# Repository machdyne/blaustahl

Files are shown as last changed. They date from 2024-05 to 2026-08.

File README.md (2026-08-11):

# Blaustahl Storage Device

The Blaustahl USB dongle provides long-term storage for 7,680 characters of text, backed by non-volatile FRAM memory — no batteries, no wear-out from repeated writes, and no risk of losing data if the device is unplugged. Simply plug it into your computer and open any serial communications program that supports VT100 emulation (PuTTY, Tera Term, Minicom, screen, etc.) to access the built-in editor.

Beyond the FRAM editor, Blaustahl also includes a small flash filesystem for storing files, a file browser and viewer, a built-in text editor, password-protected encryption, file transfer over XMODEM, and a full Scheme programming environment — all accessible over the same USB serial connection, no drivers or extra software required.

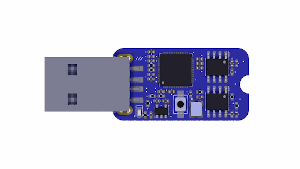
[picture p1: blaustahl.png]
Blaustahl


This repo contains schematics, PCB layouts, firmware, and a 3D-printable case.

Find purchasing information on the [Blaustahl product page](https://machdyne.com/product/blaustahl-storage-device/).

> **This is an early beta of firmware v0.1.0.** Most features described here are stable and well-tested, but as with any beta, please back up anything important and report anything that looks wrong. See firmware-0.0.x for the old firmware.

## Connecting Blaustahl

The following sections describe how to connect to Blaustahl on different operating systems. Once connected, press **CTRL-G** at any time to view the on-device help screen.

### Linux

1. Install screen or minicom:

```
$ sudo apt install screen
$ sudo apt install minicom
```

2. After plugging in Blaustahl, find the device:

```
$ dmesg | grep ACM
```

3. Connect to the device (for example):

```
$ screen /dev/ttyACM0
or
$ minicom -D /dev/ttyACM0
```

If the device is already plugged in and you see nothing, you may need to press CTRL-L to refresh the display.

### OS X

1. Open the Terminal application.

2. After plugging in Blaustahl, find the device:

```
$ ls /dev/tty.usbmodem*
```

3. Connect to the device (for example):

```
$ screen /dev/tty.usbmodem1234561
```

### Windows

1. Download and install [PuTTY](https://www.chiark.greenend.org.uk/~sgtatham/putty/latest.html).

2. After plugging in Blaustahl, find the device by opening Device Manager and looking under "Ports (COM & LPT)" for "USB Serial Device (COMx)".

3. Open PuTTY, set connection type to Serial, enter COMx (e.g. COM4) in the serial line box, and press Open.

## The menu bar

Everything in Blaustahl is reached from one menu bar across the top of the screen:

```
/// | EDITOR: [FRAM] [SRAM] | [VIEWER] [FILES] [CLI] [HELP] |   MODE: [TEXT] [HEX]
```

Press **CTRL-T**, **ESC-ESC**, or a single **ESC** (pause briefly) to open it from anywhere. Use the arrow keys to move between items and Enter to select one, or Esc to close the menu without changing anything.

- **FRAM** / **SRAM** — the built-in grid editor, for the device's permanent (FRAM) or temporary (SRAM) storage.
- **VIEWER** — a read-only viewer for files stored on the flash filesystem.
- **FILES** — browse and manage files on the flash filesystem.
- **CLI** — a command-line interface, including a full Scheme programming environment.
- **HELP** — the same help screen as CTRL-G.
- **MODE: TEXT / HEX** — switches how the grid editor displays data.

Pressing **CTRL-F** from anywhere jumps straight to FILES, skipping the menu.

## The grid editor (FRAM & SRAM)

The grid editor shows 7,680 bytes as a fixed 80x24 grid, split across four pages (PGUP/PGDN to flip between them — there's no scrolling within a page). Move the cursor with the arrow keys, or jump to the start/end of the current row with Home/End.

**FRAM** is the device's permanent, non-volatile storage — this is what survives being unplugged, and what the device is for. **SRAM** is a second, identical-sized scratchpad you can use the same way, but its contents are lost whenever the device is unplugged or power-cycled — a good place for anything temporary you don't want to persist.

| Keypress | Action |
| --- | --- |
| CTRL-W | Toggle write mode, or commit staged edits if editing encrypted FRAM |
| CTRL-B | Toggle buffer mode (see "Encryption" below) |
| CTRL-C | Start/finish copying: press once to mark the start, move the cursor to select, press again to copy |
| CTRL-V | Paste at the cursor |
| CTRL-S / CTRL-Q | Toggle the status bar |
| CTRL-L | Refresh the screen |
| CTRL-G | Help |
| PGUP / PGDN | Flip page |

By default the grid is read-only; press CTRL-W to enable editing. Whatever you type overwrites the byte under the cursor and the cursor advances — there's no insert/delete shifting, since every byte has a fixed position in the grid.

The status bar (bottom line) always shows which file you're editing, the current page, your byte offset, and the current mode — useful for keeping your bearings, especially in HEX mode.

## The file viewer

The file viewer can view text files stored in flash.

| Keypress | Action |
| --- | --- |
| UP / DOWN | Scroll one line |
| PGUP / PGDN | Scroll one screen |
| HOME | Jump to the start of the file |
| CTRL-C | Copy, same mechanism as the grid editor |

Copying in the viewer and the grid editor share one buffer, so you can copy a range from a file and paste it directly into FRAM or SRAM.

The viewer is read-only. To edit a flash file, use the CLI's `te` command instead (see below).

## Files (the flash filesystem)

Blaustahl has a small flash filesystem, separate from FRAM/SRAM, for storing files — text, Scheme programs, or anything else that fits. Selecting **FILES** from the menu (or pressing CTRL-F) lists what's stored there; select a file to open it in the viewer.

## The CLI

Selecting **CLI** from the menu drops you into a command line. Type `help` for the full list at any time.

| Command | What it does |
| --- | --- |
| `info` | Firmware version, FRAM/SRAM status, flash usage, and memory diagnostics |
| `ls` | List files on the flash filesystem |
| `rm <filename>` | Delete a file (asks for confirmation) |
| `rename <old> <new>` | Rename a file |
| `format` | Erase the entire flash filesystem (asks for confirmation) |
| `password` | Set, change, or enter a password for FRAM encryption (see below) |
| `disable_encryption` | Turn off FRAM encryption |
| `view <filename>` | Open a flash file in the viewer |
| `te <filename>` | Open a flash file in the text editor |
| `xmodem_up <filename>` | Receive a file from your computer via XMODEM |
| `xmodem_down <filename\|fram\|sram>` | Send a file, or a full copy of FRAM/SRAM, to your computer via XMODEM |
| `load <filename>` | Run a Scheme program stored on the flash filesystem |
| `firmware_update` | Enter USB bootloader mode to install new firmware (asks for confirmation) |
| `snapshot_fram` | Save a full copy of current FRAM contents to a flash file (`fram_snapshot.bin`) |

Anything typed that isn't one of the commands above is evaluated as **Scheme** — the CLI doubles as a full programming environment. See "Writing programs" below.

## Writing and running programs

Blaustahl includes a small text editor (`te`) for writing plain text or code directly on the device, and a built-in Scheme interpreter for running it.

1. From the CLI, run `te myprogram.scm` to create and edit a new file (files can be up to 32KB).
2. Write your program, save, and exit back to the CLI.
3. Run it with `load myprogram.scm`.

The interpreter comes with a standard library (`map`, `reduce`, `filter`, `sort`, and many more list, string, and math procedures) loaded automatically, alongside the usual Scheme built-ins. You can also just type expressions directly at the CLI prompt to try things out interactively — it's a normal REPL. Typing `(dump)` lists every currently available procedure and variable, if you want to see what's on hand.

## Transferring files

Blaustahl supports the standard XMODEM protocol for moving data to and from your computer, using any XMODEM-capable terminal program.

- **`xmodem_up <filename>`** receives a file from your computer and saves it to the flash filesystem. Start the command on the device, then start your terminal's "send file" (XMODEM) action.
- **`xmodem_down <filename>`** sends a flash file to your computer the same way, in reverse.
- **`xmodem_down fram`** or **`xmodem_down sram`** sends a complete copy of FRAM or SRAM (all 8,192 bytes) to your computer — a reliable way to back up or restore your data in one shot.

Uploads are limited to 32KB, the same as the text editor's file size limit.

Both directions can take a little while to start, since the handshake deliberately waits several minutes for you to get your terminal program's transfer dialog open — no need to rush.

## Encryption

FRAM contents can be protected with a password. This is entirely optional and off by default.

- Run **`password`** from the CLI to set one. Once set, FRAM is encrypted and locked whenever the device isn't actively unlocked — the grid editor will show **LOCKED** until you unlock it.
- Run **`password`** again while locked to unlock it for the session by entering your password.
- Run **`password`** again while unlocked to change it to a new one.
- Run **`disable_encryption`** to remove encryption entirely and return FRAM to plain, unprotected storage.

FRAM encryption uses strong, modern encryption (ChaCha20-Poly1305). **There is no way to recover encrypted FRAM data if you forget the password** — treat it the same way you'd treat any other password you can't reset.

Encryption only applies to FRAM. SRAM and the flash filesystem are never encrypted.

While FRAM is unlocked, edits are staged in a buffer rather than written immediately — this is what CTRL-B (toggle buffer mode) and the buffer indicator on the status bar refer to. Press CTRL-W to commit staged changes to FRAM.

## Programmatic access (SRWP)

For scripts and programs that need to read or write FRAM directly — rather than a person using the on-device editor — Blaustahl exposes **SRWP** (Simple Read/Write Protocol), a small binary protocol over the same USB serial connection. It gives raw, byte-level access to the full 8,192 bytes of FRAM.

SRWP operates below the encryption layer described above — it always reads and writes the raw bytes on the chip, whether or not FRAM encryption is enabled. If you're writing your own tooling against Blaustahl, this is the interface to use; see [`docs/srwp.md`](docs/srwp.md) for the full protocol reference, and the [original protocol specification](https://github.com/binqbit/serialport_srwp) it's based on.

## Firmware updates

Run **`firmware_update`** from the CLI to enter USB bootloader mode (this asks for confirmation first, since anything not yet committed will be lost). You can also hold the button on the device while plugging it in. Once in bootloader mode, update the firmware by dragging and dropping a new `.uf2` file onto the device, which will appear as a USB drive.

If you're developing the Blaustahl firmware, you can use `cmake -DDEV ..` to enable CTRL-Y as an alternative option for quickly switching to bootloader mode.

Blaustahl ships with `ship/blaustahl_cdconly.uf2` installed — a simple USB-CDC (serial) device, which is what makes it work with an ordinary terminal program on any platform with no special drivers.

### Building from source

If you'd like to build the firmware yourself and have [pico-sdk](https://github.com/raspberrypi/pico-sdk) installed:

```
$ git submodule update --init --recursive
$ cd firmware/blaustahl
$ mkdir build
$ cd build
$ cmake ..
$ make
```

If you'd like to pre-load files onto the flash filesystem as part of a build (rather than uploading them one at a time with `xmodem_up` afterward), `tools/mkimage` builds a littlefs image from a directory of files:

```
$ tools/mkimage dist/ littlefs.bin
```

Write it to the device with [picotool](https://github.com/raspberrypi/picotool), alongside the normal firmware, while the device is in bootloader mode:

```
$ picotool load build/blaustahl_cdconly.uf2
$ picotool load littlefs.bin -t bin -o 0x10200000 -v
```

We provide an example `littlefs.bin` containing a subset of the [Ark Codex](https://github.com/machdyne/ark) as well as other documentation.

The `-v` verifies the write by reading it back immediately. Two separate `picotool load` calls, not a combined file — a real RP2040 bootrom erratum (RP2040-E14) can silently drop part of a UF2 that spans multiple, non-adjacent regions, and `picotool` avoids it entirely by writing directly rather than going through that code path.

## Future data recovery

In the event that the USB interface were to become obsolete or the RP2040 were to become non-functional, it should still be possible to recover the FRAM data using a SOP-8 test clip. The FRAM IC is marked "RS64".

One way to achieve this today is to load the Blaustahl firmware onto a Raspberry Pi Pico using the same SPI GPIOs as shown in the schematics, then hold the Blaustahl boot button while attaching a test clip to the FRAM IC. The grid editor or SRWP can then be used to recover the FRAM data.

## License

The contents of this repo are released under the [Lone Dynamics Open License](LICENSE.md).

Note: You can use these designs for commercial purposes, but we ask that instead of producing exact clones, you either replace our trademarks and logos with your own or add your own next to ours.

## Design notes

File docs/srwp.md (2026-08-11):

# SRWP -- Simple Read/Write Protocol

SRWP gives a host machine raw, byte-level read/write access to
Blaustahl's FRAM over the same USB CDC (serial) connection used for
the interactive terminal UI. It's the primary machine-to-machine API
for the device: with the USB Composite firmware variant and its
separate vendor-class interface removed, CDC is the only USB
interface Blaustahl exposes, and SRWP is how a program -- as opposed
to a human typing at a terminal -- talks to it.

Protocol origin: [binqbit/serialport_srwp](https://github.com/binqbit/serialport_srwp).
This document describes Blaustahl's own implementation, including
where and why it deliberately diverges from or extends that reference.

## Design: raw, encryption-unaware, all 8KB

SRWP operates directly on the full physical FRAM chip -- all 8192
bytes, address 0 through 8191 -- with no awareness of:

- **FRAM encryption.** If FRAM is encrypted, an SRWP read returns raw
  ciphertext, not plaintext. An SRWP write goes straight to the chip;
  if FRAM happens to be encrypted at the time, that write will corrupt
  it beyond recovery (the AEAD authentication tag will no longer
  match the ciphertext, and there is no way to recover the original
  content). This is a deliberate, accepted tradeoff for the current
  protocol revision, not an oversight -- extending SRWP itself to be
  password/encryption-aware is a possible future direction, not
  something this revision attempts.
- **The grid editor's buffer mode.** The interactive editor stages
  edits in its own RAM buffer before committing them to FRAM (see
  storage.c). SRWP reads and writes bypass that buffer entirely,
  talking straight to the chip. A write from SRWP while the editor has
  an active, uncommitted buffer will not be reflected in that buffer,
  and a later commit from the editor will silently overwrite whatever
  SRWP just wrote. The firmware surfaces a one-time warning
  ("SRWP WROTE FRAM") on the grid editor's status line the next time
  it redraws, to catch a human's attention -- see
  `editor_notify_srwp_write()` in editor.c. It does not attempt to
  reconcile the buffer automatically.

Given both of the above, SRWP is best understood as a way to treat
FRAM as a flat 8KB block device, similar in spirit to writing directly
to a disk's raw device node -- not as a way to interact with
Blaustahl's own file/encryption model. If your use case needs
encryption-aware access, use the interactive terminal UI (grid editor
or CLI) instead, at least until SRWP is extended to support it.

## Wire framing

Every SRWP command starts with a single `0x00` byte. This is checked
centrally, before any other input handling, in `editor_yield()`
(editor.c) -- the very first byte of every read is checked, and if
it's `0x00`, control hands off to `srwp()` to read and process exactly
one full command before returning. This means SRWP can be sent at any
time, from any UI mode (grid editor, viewer, file browser, CLI,
help screen, menu) -- it always takes priority over whatever the
interactive UI happens to be doing when the byte arrives, since the
leading `0x00` is not a meaningful keystroke on its own.

The consequence: an SRWP session and an interactive human session
cannot usefully coexist moment-to-moment on the same serial
connection. Use one or the other at a time.

All multi-byte integers (addresses, lengths) are 4-byte,
**little-endian** encoded.

## Commands

### CMD_TEST (`0x00`)

Request: `0x00 0x00 <len:u32> <data:len bytes>`
Response: `<data:len bytes>` -- the same bytes, echoed back exactly.

A pure loopback test. Touches no FRAM at all; useful for verifying the
connection and framing are working before attempting a real
read/write.

### CMD_READ (`0x01`)

Request: `0x00 0x01 <addr:u32> <len:u32>`
Response: `<data:len bytes>`

Reads `len` bytes starting at `addr`. Always replies with exactly
`len` bytes, even if the requested range runs past the end of FRAM --
any portion beyond address 8191 is zero-filled in the response rather
than the reply being short. (The protocol has no way to signal "here's
less than you asked for"; a host waiting on a fixed-length reply that
never fully arrives would simply hang. Zero-padding avoids that.)

### CMD_WRITE (`0x02`)

Request: `0x00 0x02 <addr:u32> <len:u32> <data:len bytes>`
Response: none.

Writes `len` bytes starting at `addr`. Bytes that would fall at or
past address 8192 are read from the host (so the stream stays framed
correctly for whatever command comes next) but discarded rather than
written. Since this command has no reply at all, there is no way to
signal that part of a write was rejected -- if you write near the end
of FRAM, read the result back afterward to confirm what actually
landed.

### CMD_SIZE (`0x0a`) -- firmware-specific extension

Request: `0x00 0x0a`
Response: `<size:u32>` -- always `8192`.

Not part of the documented upstream protocol. Included because it's
useful and was already present in earlier versions of this firmware;
kept as a Blaustahl-specific extension. A host that only implements
the three commands above can safely ignore this one.

## Hardening notes (relative to the original implementation)

The following issues existed in the SRWP implementation this firmware
started from, and were fixed as part of hardening it into the
project's primary API surface:

1. **Unbounded stack allocation.** The original sized a buffer
   directly from the host-supplied length (`uint8_t buf[len]`, a
   variable-length array) with no bounds check at all -- a genuine
   stack-smashing risk on an embedded target with a small, largely
   unknown stack budget. Every transfer now streams through a small,
   fixed 128-byte static buffer instead, regardless of the requested
   length.

2. **No bounds checking against FRAM's actual size.** Addresses and
   lengths are now checked against the full 8192-byte chip, with the
   comparison written to avoid integer overflow (an address and length
   that together overflow past `UINT32_MAX` can no longer be
   miscomputed as "in range").

3. **Fragile multi-byte reads.** The original read 4-byte values
   (addresses, lengths) with a single, one-shot read call and gave up
   immediately -- silently losing whatever partial data had already
   arrived -- if fewer than 4 bytes came back in that one call. Under
   ordinary USB packet fragmentation this could desync the parser
   mid-command. Every multi-byte value is now accumulated through a
   proper byte-at-a-time loop with a bounded per-byte timeout, the
   same philosophy already used by this firmware's XMODEM
   implementation: once a command has genuinely started, it's correct
   to wait a reasonable bounded time for the rest of it, rather than
   abandon the parse on the first timing hiccup.

4. **Implementation-defined byte-order handling.** The original read
   raw bytes directly into a `uint32_t` via a pointer cast, relying on
   the host and device happening to agree on byte order through
   undefined/implementation-defined pointer-aliasing behavior.
   Little-endian encoding/decoding is now explicit.

## Testing

See `tools/test_srwp.py` for a standalone, repeatable test suite that
exercises all of the above -- basic echo, round-trip read/write,
boundary addresses (0, 8191, exactly at the 8192 edge),
out-of-bounds reads and writes, command sequencing, larger multi-chunk
transfers, and a deliberately malformed length to confirm the firmware
aborts safely rather than hanging or crashing.

**The test suite writes to FRAM, including address 0 and the very
last byte.** Run against real hardware, it backs up the full 8KB via
SRWP's own read command before touching anything, and restores it
afterward -- including if a test fails partway through -- so it's
safe to run against a device that already has real data on it. The
backup is also written to a local timestamped file as a second line
of defence. See the script's own docstring for usage.

```sh
pip install pyserial
python3 tools/test_srwp.py --port /dev/ttyACM0
```

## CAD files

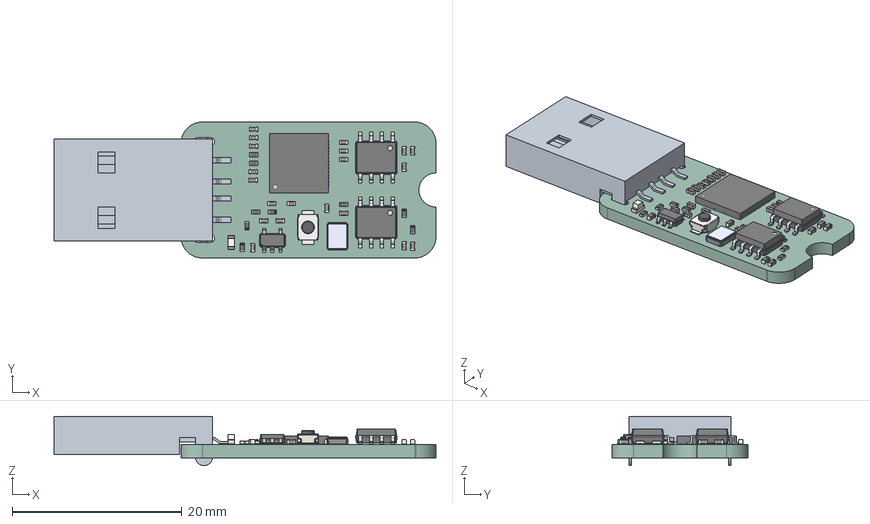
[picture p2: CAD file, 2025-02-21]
case/blaustahl.step
45.0 x 16.0 x 5.80 mm
R_0402_1005Metric x 9
C_0402_1005Metric x 20
TSOP_5_165x305mm_P095mm
ECS-540-8-33-JTN-TR
LED_0603_1608Metric
QFN-56-1EP_7x7mm_Pitch0.4mm
SOIC_8_39x49mm_P127mm x 2
SW_SPST_B3U-1000P
ssb_PCB

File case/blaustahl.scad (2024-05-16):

/*
 * Blaustahl Case
 * Copyright (c) 2024 Lone Dynamics Corporation. All rights reserved.
 *
 * required hardware:
 *  - 1 x M2.5 x 10mm countersunk bolt
 *  - 1 x M2.5 nut
 *
 */
 
$fn = 30;

box_width = 18;
box_length = 37;
box_height = 11;
box_thickness = 2.0;

lid_thickness = 3;

cutout_width = 16.10;
cutout_length = 33.60;
cutout_height = 8.5;

cutout_usb_width = 12;

board_height = 1.4;

roundness = 1;

color([0.8,0.8,0.8]) ldp_lid(3.5);
ldp_board(-1.75);
translate([0,0,-0.5]) ldp_case();
ldp_spacer(0);

// m2.5 bolt
//translate([0,-13,-4.25]) color([1,0,0]) cylinder(d=2.5, h=8, $fn=36);

// m2.5 nut
//translate([0,-13,-5.55]) color([1,0,0]) cylinder(d=5.8, h=2.4, $fn=6);

module ldp_spacer(o)
{
	difference() {
		union() {
			translate([0,-13.5,o-0.75]) color([0,0,1]) cylinder(d=6, h=3, $fn=36);
			translate([0,-13.5,o-2.3]) color([0,0,1]) cylinder(d=4, h=2.5, $fn=36);
		}
		translate([0,-13.5,-4.25]) color([1,0,0]) cylinder(d=3, h=8, $fn=36);
	}
}

module ldp_board(o)
{
	
	difference() {
		union() {
			translate([0,2,o])
				color([0.0,0.8,0.0]) cube([16, 30, 1.6], center=true);
			translate([0,23,o+1.45])
				color([0.9,0.9,0.9]) cube([12, 15, 4.5], center=true);
		}
		translate([0,-13,-10]) cylinder(d=4.2, h=100);
	}
	
}

module ldp_case()
{

	//color([0,1,0]) cube([box_width,box_length,box_height], center=true);
	
	difference() {

		
		minkowski() {
			cube([box_width-(roundness*2),box_length-(roundness*2),box_height-(roundness*2)],
				center=true);
			sphere(roundness);
		}
	
		translate([0,0,(box_height-cutout_height)/2])
			cube([cutout_width,cutout_length,cutout_height], center=true);

		// USB cutout
		translate([0,15,3])
			cube([cutout_usb_width,10,10], center=true);

		// bolt hole
		translate([0,-13.5,-5]) cylinder(d=2.75, h=100, $fn=36);
		
		// nut cutout
		translate([0,-13.5,-5.5]) rotate(30) cylinder(d=6.25, h=2.5, $fn=6);
		
		// lid notch cutout
		translate([0,box_length/2-1.75,3.5])
			rotate([0,90,0]) cylinder(d=2.25, h=14.25, center=true);
				
	}

	// board support
	translate([0,0,-3])
		cube([16,16,2.25], center=true);

	difference() {
		
		translate([0,-10,-2.75])
			cube([8,15,1.75], center=true);		

		// bolt hole
		translate([0,-13.5,-5]) cylinder(d=2.75, h=100, $fn=36);
		
		// nut cutout
		translate([0,-13.5,-5.25]) rotate(30) cylinder(d=6.25, h=2.5, $fn=6);
	}
	
}

module ldp_lid(o)
{
	/*
	rotate(270)
		translate([-3,-2.25/2,o+0.25])
			linear_extrude(1.25)
				resize([25,2.25,1.25]) text("BLAUSTAHL", size=10, spacing=1.75, halign="center",
					font="Liberation Sans:style=Bold");
	*/
	
	union() {
		translate([0,box_length/2-1.5,o])
			cube([11.75,1,lid_thickness], center=true);
		translate([-5.875,box_length/2-1.25,o+0.25])
			rotate([0,90,0]) cylinder(d=2.5, h=11.75);
		translate([0,box_length/2-1,o-0.5])
			cube([11.75,2,2], center=true);
	}
			
	difference() {

		
		union() {
			
			translate([0,0,o]) {
				cube([box_width-box_thickness,box_length-box_thickness-1.5,lid_thickness], center=true);
			}
			
			translate([0,box_length/2-1.75,o-0.5])
				rotate([0,90,0]) cylinder(d=2, h=14, center=true);

		}
		/*
		rotate(270)
			translate([-2.5,-2/2,o+1])
				linear_extrude(1.25)
					resize([25,2,1.25]) text("BLAUSTAHL", size=10, spacing=1.75, halign="center",
						font="Liberation Sans:style=Bold");
		*/
		translate([0,-13.5,3.5]) cylinder(d=5, h=100);
		translate([0,-13.5,-5]) cylinder(d=2.75, h=100);
		
	}
	
}

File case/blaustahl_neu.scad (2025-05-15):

/*
 * Blaustahl Case Neu Edition
 * Copyright (c) 2025 Lone Dynamics Corporation. All rights reserved.
 *
 * required hardware:
 *  - 1 x M2.5 x 10mm countersunk bolt
 *  - 1 x M2.5 nut
 *
 */
 
$fn = 30;

box_width = 19;
box_length = 37;
box_height = 10.5;
box_thickness = 2.0;

lid_thickness = 3;

cutout_width = 16.10;
cutout_length = 44;
cutout_height = 5.5;

cutout_usb_width = 12;

board_height = 1.4;

roundness = 2;

toladj = 0.25;

ldp_board(-0.5);
translate([0,0,-0.5]) ldp_case();
translate([0,0,-0.25]) ldp_endcap();

// m2.5 bolt
//translate([0,-13.5,-6.25]) color([1,0,0]) cylinder(d=2.5, h=12, $fn=36);

// m2.5 nut
//translate([0,-13.5,-6.55]) rotate(30) color([1,0,0]) cylinder(d=5.8, h=2.4, $fn=6);

module ldp_endcap()
{
    		 	
	difference() {
		union() {
			translate([0,-13.5,-0.5]) color([0,0,1]) cylinder(d=6, h=3.5, $fn=36);
			translate([0,-15.75,-0.25]) cube([16.1,5.5,6.5], center=true);
		}
		translate([0,-13.5,-4.25]) color([1,0,0]) cylinder(d=3, h=8, $fn=36);
        color([1,0,0]) translate([0,0,-5.5]) cube([6.5,100,6], center=true);

	}
}

module ldp_board(o)
{

	difference() {
		union() {
			translate([0,2,o])
				color([0.0,0.8,0.0]) cube([16, 30, 1.6], center=true);
			translate([0,23,o+1])
				color([0.9,0.9,0.9]) cube([12, 15, 4.5], center=true);
		}
		translate([0,-13,-10]) cylinder(d=4.2, h=100);

	}
	
}

module ldp_case()
{

	difference() {
		
		minkowski() {
			cube([box_width-(roundness*2),box_length-(roundness*2),box_height-(roundness*2)],
				center=true);
			sphere(roundness);
		}	
        
		translate([0,-5,(box_height-cutout_height)/2-2])
			cube([cutout_width+toladj,cutout_length,cutout_height], center=true);

		translate([-5.675,-5,(box_height-cutout_height)/2-3])
			cube([5,cutout_length,cutout_height], center=true);
		
		translate([5.675,-5,(box_height-cutout_height)/2-3])
			cube([5,cutout_length,cutout_height], center=true);

		// USB cutout
        translate([0,15,0.8])
            cube([cutout_usb_width+toladj,10,4.6+toladj], center=true);
        
		// bolt hole
		translate([0,-13.5,-5]) cylinder(d=2.75+toladj, h=100, $fn=36);
		
		// nut cutout
		translate([0,-13.5,-5.75]) rotate(30) cylinder(d=6+toladj, h=2.5, $fn=6);
    
        // lid notch cutout
        translate([0,-13.5,4.5]) cylinder(d=5+toladj, h=100);

//        translate([-1.5,2.5,5.1]) rotate([0,0,270])
//            linear_extrude(0.3)
//                text("BLAUSTAHL", size=3, halign="center", font="Lato Black");

	}

}

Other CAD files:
case/blaustahl_alt.scad

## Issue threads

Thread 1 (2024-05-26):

Windows doesn't recognize USB composite firmware

machdyne, 2024-05-26:
Windows fails to recognize the device when running the (default) USB composite firmware.

As a workaround there is now an alternative CDC-only firmware that is successfully recognized by Windows.

machdyne, 2025-01-28:
Hello. If you haven't yet, you might want to try all possible serial ports, just in case.

Also you might try pressing CTRL-L to force a redraw after connecting.

If you have access to another Linux or OS X computer, you could try it there, and if it works you can press CTRL-Y to enter DFU bootloader mode.

In the worst case, you can open the case, hold the button, and then insert the device, in order to enter the DFU bootloader mode. You can then drag-and-drop the cdconly UF2 firmware file.

Blaustahl should ship with the cdconly firmware, but it's possible that updating the firmware may solve the issue.

gund, 2025-01-31:
I've managed to connect to the USB on macos and was able to write data to it as well as updated the firmware to latest cdconly version. So we know that device itself is functioning correctly.
But even after that on windows I still cannot connect to it, not in PuTTY not via WSL, nothing happens and I still see it as a COM2 device when connected.
Any ideas what else I could try to figure out why it's not connecting from windows?

machdyne, 2025-01-31:
It will test the latest firmware in Windows and report back. I believe in the past with PuTTY I have set connection type to serial, serial line to COM2, speed 115200 and it just worked.

KrypticKahos, 2025-05-12:
I know this is a somewhat older thread but I'm having similar issues with my device. I was able to connect and write data to the device from OS X, but have had no success with windows. I have updated the firmware and changed settings, com port numbers, baud rates and no connection on windows. In putty I input my settings and press open and nothing happens.

machdyne, 2025-05-13:
I have tested the latest firmware with Windows 11 and it does work with PuTTY. Can you let us know what version of Windows you're using? Can you see the device in Device Manager as a COM port?

KrypticKahos, 2025-05-14:
> I have tested the latest firmware with Windows 11 and it does work with PuTTY. Can you let us know what version of Windows you're using? Can you see the device in Device Manager as a COM port?

I do see the device as a COM port. Windows version 10.0.26100 Build 26100.

Besides setting the COM port and baud speed, what are the other setting being used?

machdyne, 2025-05-15:
Thanks @KrypticKahos.

The COM port should be the only setting that needs to be changed.

There is new firmware available that may solve the Windows issue:

https://github.com/machdyne/blaustahl/raw/refs/heads/main/firmware/blaustahl_cdconly-0.0.9.uf2

The previous firmware was not correctly specifying the USB device subclass for Windows, which doesn't seem to matter on Windows 11 but could be the cause of the issue on Windows 10.

Also make sure to press CTRL-L after connecting with PuTTY to redraw the screen.

If none of that works, it might be worth trying another terminal app like Tera Term.

KrypticKahos, 2025-05-15:
@machdyne

I updated the firmware and still had no luck with putty. I did try Tera Term and everything is working as expected.

Thanks for the support.

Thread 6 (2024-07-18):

Firmware needed fro operation

jasen-b, 2024-07-18:
You need to also store the firmware in durable storage, else when the flash holding the firmware forgets it the device is bricked.

akrabu, 2024-07-18:
Did you catch the "Future data recovery" section at the bottom of the main page?  It is possible to recover directly from the FRAM chip.

machdyne, 2024-07-18:
This is a common criticism that I saw after Blaustahl was released. One of the main ways I imagined Blaustahl being used, was that a user would make regular edits over several years, and then at some point stop. After that, it would become a matter of data recovery in the distant future.

However, if the flash became corrupt after 20+ years it may still be possible to reflash the firmware. The MCU has a USB bootloader in ROM that's essentially unbrickable. We have plans to make all of our firmware/source, documentation and schematics available for 100+ years.

And then as @akrabu mentioned, it is possible to recover the data directly from the FRAM chip if the MCU, flash or PCB don't work.

It's not clear how common USB-A connectors will be decades from now, so specialized equipment for data recovery may be necessary regardless.

Luckily Blaustahl has received a decent amount of press coverage that may be discoverable in the future so if someone finds a Blaustahl they should be able to determine what it is and that it might be worth trying to recover data from it.

Closed 2025-01-22.

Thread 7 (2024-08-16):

Experimental encryption support

machdyne, 2024-08-16:
There is now a [branch](https://github.com/machdyne/blaustahl/tree/feature/encryption) with experimental authenticated encryption support.

There is no firmware image available yet, so you will need to build the branch from source if you want to try this. **Please don't use this if you have any valuable information on the device as it is still very experimental and total loss of data is very likely to occur.**

I'm making this available now because it will require significant testing and auditing in order to be useful to most users. If you run into any issues or find problems in the code please let me know.

A quick explanation of how it works:

In order to enable encryption, press CTRL-P and enter a password or passphrase.

The device generates a random salt and stores it in FRAM. It appends the salt to your chosen password and then hashes them using SHA256. The result is the encryption key.

Blaustahl then encrypts the current FRAM contents using ChaCha20-Poly1305 and stores the metadata (nonce and authentication tag) and encrypted data in FRAM.

While encryption is enabled, the device uses buffered mode, in which all editing takes place in an SRAM buffer, that can be encrypted and written to FRAM by pressing CTRL-W.

Each time data is written, the nonce is incremented and the authentication tag is updated.

When you remove the device and plug it back in, you will need to press CTRL-P in order to enter your password, before you're able to view or edit text.

It is possible to disable encryption after entering a valid password by using the command line interface (CTRL-C):

Blaustahl> disable_encryption

This causes Blaustahl to disable encryption and write the plaintext to FRAM. It's then possible to use either buffered mode or direct mode (which uses CTRL-W to toggle read-only/read-write).

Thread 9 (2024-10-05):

Configuring machdyne blaustahl storage device for direct data access via serial port

binqbit, 2024-10-05:
I have a question regarding the possibility of configuring the Machdyne Blaustahl Storage Device to enable direct data reading and writing through my custom software, without using a terminal interface. Could you please provide guidance or documentation on how to effectively integrate this functionality via the serial port, if this is possible?

machdyne, 2024-10-06:
Hello. I plan to create a simple SDK/API for this but at the moment the best example I can offer is the [bs](https://github.com/machdyne/blaustahl/tree/main/sw) utility, which uses libusb to communicate with the composite firmware using a USB "vendor class" interface and allows reading/writing of the FRAM from the host computer.

Another possibility would be to add a mode to the firmware that  provides something like an AT command set for reading and writing data. That would also work on the CDC-only firmware.

If you'd like to provide any more details about what you're trying to accomplish I may be able to help with your specific case.

binqbit, 2024-10-07:
Hi,
If anyone still has a similar question, I've found a simple solution and already implemented it. In my fork of the repository, all necessary changes have been made to the driver to support a simple read/write protocol, and the drivers are ready to use. Here are the links for those who need them:

1. Fork of the repository with updated drivers: [blaustahl](https://github.com/binqbit/blaustahl).
2. Example code of the application implementing the protocol: [serialport_srwp](https://github.com/binqbit/serialport_srwp).

machdyne, 2024-10-10:
I think this is a great solution. Feel free to submit a PR if you'd like.

Closed 2024-10-07.

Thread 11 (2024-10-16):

Automatic launch of built-in application on device when connected to a computer

binqbit, 2024-10-16:
Hello,

I have a question regarding the potential use of the Machdyne Blaustahl Storage Device. Is it possible to modify the driver or reflash the flash drive so that when the device is connected to a computer, it automatically detects the operating system and launches the corresponding pre-installed program?

Currently, I have developed a special application for this device — [password manager (svpi)](https://github.com/binqbit/svpi). Manually installing and launching the application each time the device is connected seems inconvenient. I aim for the password manager to launch automatically when the device is connected to any computer.

I would be extremely grateful for any assistance or advice on this matter.

machdyne, 2024-10-17:
On Linux I think you can set up a udev rule to launch a program when a device is connected. On old versions of Windows you could use an autorun.inf file (assuming a USB-MSC device was added) to launch a program when the device is connected, but getting that to work would probably require a custom driver.

I don't think there's a generic way to do this on the device itself, it would have to be set up on the OS.

binqbit, 2024-10-27:
I wanted to specify that in standard USB devices, it's indeed possible to use an autorun.inf file to specify which program should launch upon connection. However, the Machdyne Blaustahl Storage Device is a specific device, and as I understand it, this approach isn't applicable.

I'm interested in how to organize the automatic launch of a program specifically on this device. Is there a possibility of creating a custom driver or modifying the firmware to implement this feature?

machdyne, 2024-10-27:
If autorun.inf would solve your problem, you might try modifying the composite firmware and adding a MSC interface.

Here's an example for emulating a FAT-formatted drive in order to serve a read-only file:

https://github.com/hathach/tinyusb/tree/master/examples/device/cdc_msc

Keep in mind though that the composite firmware isn't currently recognized by Windows, so you'd need to solve that problem also, which may require creating a custom driver in order to get the composite device recognized. I don't know much about Windows drivers.

I guess some distros of Linux may also support autorun files, so you could use the same concept there with MSC. But the udev solution would probably be much simpler on Linux.

Closed 2025-01-22.

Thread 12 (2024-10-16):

Editor freezes when firmware is built with latest pico-sdk

machdyne, 2024-10-16:
There is some output when the editor starts but then it freezes.

I think this is related to cdc_out.c but will need to investigate further.

machdyne, 2024-10-17:
The firmware is now building with pico-sdk 1.5.1 but not 2.0.0. I recommend using pico-sdk 1.5.1 until the cause of this issue is determined.

machdyne, 2025-01-20:
This appears to be fixed with pico-sdk 2.1.0.

Closed 2025-01-20.

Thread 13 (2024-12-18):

Hardware FRAM IC revision/upgrade to 8Mbit

Firemission1343, 2024-12-18:
First off very cool project! Found your project from LTT video and wanted to look more into it.

Currently from what I can tell, the FRAM IC used is the MB85RS64 (blaustahl_v0.pdf says MB85RS16) which is at 64Kbit ([Datasheet](https://www.lcsc.com/datasheet/lcsc_datasheet_2112091730_FUJITSU-MB85RS64PNF-G-JNERE1_C8741.pdf)).
The largest other IC in the same 8-SOIC package is a 8Mbit CY15B108QN-40SXI from Infineon Technologies ([Datasheet](https://www.infineon.com/dgdl/Infineon-CY15B108QN_CY15V108QN_Excelon(TM)_LP_8-Mbit_(1024K_X_8)_Serial_(SPI)_F-RAM-DataSheet-v11_00-EN.pdf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)).

It would be quite an upgrade from the 64Kbit size limitation, to a 8Mbit at 125x increase in memory at about only 20x in cost (ignoring other costs from board changes)
There are some important differences like clock frequency, supply voltage, and Pin 7 but would it be feasible to create a V2 using a larger FRAM ic?
Personally, the 8KB is just a tad bit too limited for any uses cases I would want to use.

Supermath101, 2024-12-18:
With FRAM chips that are that big on the market, such as the RAMXEED MB85RQ8MX ([Datasheet](https://www.ramxeed.com/assets/images/products/datasheet/FeRAM/s1/MB85RQ8MX-DS1v1-E.pdf)), you could likely ditch the on-board QSPI flash chip altogether, and only have the rp2040, FRAM, and other miscellaneous components.

machdyne, 2024-12-18:
@Firemission1343 I am planning a higher capacity version, possibly with a different name and different firmware. A filesystem starts to make sense at some point. Blaustahl does use MB85RS64, the MB85RS16 was used in [Stahl](https://github.com/machdyne/stahl).

@Supermath101 I have been experimenting with all-FRAM systems as part of the [Zwölf MCU](https://machdyne.com/2024/11/15/zwolf-mcu-platform/) project. I need to test RP2040 boot compatibility with the higher capacity FRAM, but even if it doesn't work out there are FRAM-based MCUs that could make an all-FRAM device possible.

Thanks.

machdyne, 2025-01-21:
An update for anyone interested in higher capacity FRAM storage ...

I've posted some details about a higher capacity version of Blaustahl:

https://machdyne.com/product/kaltstahl-storage-device/

Depending on demand I may hand-assemble a limited number of those.

I'm also working on a long-term storage array called Ebenstahl:

https://machdyne.com/product/ebenstahl-storage-device/

akrabu, 2025-01-22:
Getting stuck on the CAPCHA trying to reserve one!

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

tailz303, 2025-01-26:
Just curious if at all possible is there some sort of hexedit or bin editing that could be done to allow bigger chips if needed? I have ordered a MB85RS4MTYPF-G-BCERE1 from mouser and am waiting for it to arrive. It is a seemingly compatible spi 4mbit sop8 chip. I looked at the firmware and tried to run strings, use uf2conv.py and some other noobile things I could think of on it to see if I could find some easy to modify logic that limits the max size. Currently its just for fun and since I have a ch341a_spi and matching sop8 clip (mainly for bios flashing) I can always undo something if broken. Basically all that to say a 500,000 ish character serial text editor f-ram thingy would be funny and cool and I want to do it but dont know if the firmware will get mad if I swap the chip.

machdyne, 2025-01-26:
Rebuilding the firmware is probably much easier, you would just need to define FRAM_BIG and increase FRAM_PAGES in blaustahl.h.

FRAM_BIG uses 24-bit addresses instead of 16-bit addresses when talking to the FRAM, which is necessary on the larger FRAMs. Because of that the default firmware won't work with the larger chips.

Keep in mind the Blaustahl is virtually unbrickable thanks to the RP2040 bootrom, you should be able to use the boot select button to access the UF2 bootloader even if the flash becomes corrupt.

As far as the MB85RS4MTYPF-G-BCERE1 is concerned, I believe it is 208mil wide which won't probably won't quite fit onto the footprint but you may be able to bend the pins and get it working.

Kaltstahl is using MB85RS2MTAPNF-G-BDERE1 which is the largest FRAM I was able to find in a 150mil wide SOP-8 package.

If you have trouble building the firmware let me know and I will make available some binaries for larger FRAM sizes.

tailz303, 2025-01-26:
I might have done something wrong. I first tested with big_fram uncommented and 16 pages, this cascaded the existing text like 40 times down the screen so I put it back to 4, same thing, then disabled big_fram all together and same thing. I put your precompiled firmware and it worked fine, so I used that to delete everything and when I put the complied firmware back on and wrote something it cascaded again. Not sure what I might have done wrong haha

machdyne, 2025-01-26:
FRAM_BIG will only work correctly with the bigger FRAMs, because it sends a 24-bit address and the smaller (8KB) FRAM expects at 16-bit address. Please let us know how the upgrade goes. Thanks.

tailz303, 2025-01-31:
After much waiting for UPS here's the results with pictures. It worked!

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

I tested and data holds integrity at page 1, 108, and 250 whereas 8 pages on the 8KB chip would repeat every 4th page. This verifies that it's communicating correctly

machdyne, 2025-01-31:
That's great, glad to see that the wider chip fits.

rcmcdonald91, 2025-01-31:
@tailz303 do you have a link for these bigger chips?

also #23

tailz303, 2025-01-31:
> That's great, glad to see that the wider chip fits.

Yeah it was pretty neat, I was able to take the "sprawl" of the legs and fold them under the chip essentially making a worse less flat wson8 chip but it fit well on the pad layout and aside from my imperfect bending soldered on well! I would have fixed it but didn't want to keep heating up the board.

> [@tailz303](https://github.com/tailz303) do you have a link for these bigger chips?

Yes! here's the one I used: [https://www.mouser.com/ProductDetail/Ramxeed/MB85RS4MTYPF-G-BCERE1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](url)

rcmcdonald91, 2025-02-03:
@tailz303 thanks!!

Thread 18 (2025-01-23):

Firmware 0.0.7 Update and Windows doesnt recognize blaustahl

Dave187420, 2025-01-23:
I just received the blaustahl and updated the firmware to 0.0.7 and now windows doesnt recognize the blaustahl anymore.
I could putty it to it fine with the shipped firmware, but now it doesnt list in device manager in win 11.
I need help please or i am just missing something.

machdyne, 2025-01-23:
Make sure you're using the blahstahl_cdconly.uf2 firmware if you need to access Blaustahl from Windows. Note that if you can no longer access the editor, you can get into bootloader mode by holding down the button while you plug the device in.

Dave187420, 2025-01-23:
okay thanks, i got it to the bootloader and drag and drop the file blahstahl_cdconly.uf2 to the file Exporer but after reboot it still doesnt show the COM & LPT Ports for win11. Do you have the Sipped firmware version to try for me?

machdyne, 2025-01-23:
Interesting, I haven't yet tested 0.0.7 on Windows but will do that. Thanks.

The 0.0.6 firmware that's been shipping on devices is now here: https://github.com/machdyne/blaustahl/tree/main/firmware/ship

machdyne, 2025-01-23:
I've now tested and updated the 0.0.7 binaries and they appear to be working.

Closed 2025-01-26.

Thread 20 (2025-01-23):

Firmware 0.0.7 not recognized under Linux

LunarLambda, 2025-01-23:
Tried to install the today-released 0.0.7 composite firmware, but it does not seem to be working. The device is not recognized at all, no messages appear in dmesg when plugging it in. Holding the button on the device when plugging it in to enter firmware update mode and downgrading to the 0.0.6 composite firmware restores functionality.

dmesg log from downgrade:

```
[  532.719517] usb 1-11: new full-speed USB device number 8 using xhci_hcd
[  532.861271] usb 1-11: New USB device found, idVendor=2e8a, idProduct=0003, bcdDevice= 1.00
[  532.861285] usb 1-11: New USB device strings: Mfr=1, Product=2, SerialNumber=3
[  532.861292] usb 1-11: Product: RP2 Boot
[  532.861297] usb 1-11: Manufacturer: Raspberry Pi
[  532.861301] usb 1-11: SerialNumber: E0C9125B0D9B
[  532.865556] usb-storage 1-11:1.0: USB Mass Storage device detected
[  532.866086] scsi host4: usb-storage 1-11:1.0
[  533.883221] scsi 4:0:0:0: Direct-Access     RPI      RP2              3    PQ: 0 ANSI: 2
[  533.884495] sd 4:0:0:0: [sdb] 262144 512-byte logical blocks: (134 MB/128 MiB)
[  533.885255] sd 4:0:0:0: [sdb] Write Protect is off
[  533.885260] sd 4:0:0:0: [sdb] Mode Sense: 03 00 00 00
[  533.886069] sd 4:0:0:0: [sdb] No Caching mode page found
[  533.886074] sd 4:0:0:0: [sdb] Assuming drive cache: write through
[  533.892312]  sdb: sdb1
[  533.892557] sd 4:0:0:0: [sdb] Attached SCSI removable disk
[  541.683437] usb 1-11: USB disconnect, device number 8
[  541.684301] device offline error, dev sdb, sector 260 op 0x1:(WRITE) flags 0x100000 phys_seg 1 prio class 2
[  541.684317] Buffer I/O error on dev sdb1, logical block 259, lost async page write
[  541.713003] FAT-fs (sdb1): unable to read boot sector to mark fs as dirty
[  542.009426] usb 1-11: new full-speed USB device number 9 using xhci_hcd
[  542.152772] usb 1-11: unable to get BOS descriptor or descriptor too short
[  542.154317] usb 1-11: New USB device found, idVendor=16c0, idProduct=05e1, bcdDevice= 2.00
[  542.154325] usb 1-11: New USB device strings: Mfr=1, Product=2, SerialNumber=3
[  542.154329] usb 1-11: Product: Blaustahl Firmware
[  542.154334] usb 1-11: Manufacturer: Lone Dynamics Corporation
[  542.154337] usb 1-11: SerialNumber: 123456
[  542.184143] cdc_acm 1-11:1.0: ttyACM0: USB ACM device
[  542.184167] usbcore: registered new interface driver cdc_acm
[  542.184168] cdc_acm: USB Abstract Control Model driver for USB modems and ISDN adapters
```

LunarLambda, 2025-01-23:
A word of thanks and appreciation though that the device seems to be safe from firmware-related bricking. That's quite reassuring, and encourages tinkering.

machdyne, 2025-01-23:
Looks like both of the 0.0.7 binaries are not working. I'll get fixed binaries up ASAP. Thanks.

machdyne, 2025-01-23:
I've tested and updated the 0.0.7 binaries. Not sure what went wrong previously.

The main change with 0.0.7 is fixed SRWP support.

LunarLambda, 2025-01-24:
Just tried, upgrade and editor works fine. Haven't tested the SRWP support yet. Thanks for the fix!

Closed 2025-01-24.

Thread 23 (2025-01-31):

MSC Support + LittleFS

rcmcdonald91, 2025-01-31:
I have a working PoC that enables block access to the FRAM.

The filesystem is https://github.com/littlefs-project/littlefs and I'm using https://github.com/littlefs-project/littlefs-fuse because there is not (yet) a kernel driver for LittleFS. I plan on implementing a kernel driver for both Linux and FreeBSD at some point. I'd like a good excuse to learn how to do that.

We only get 16 blocks (512bytes), so it's better to wrap files up in a tarball (gz compressed for bonus points).

Obviously this becomes more useful with larger FRAM chips.

machdyne, 2025-01-31:
Very cool. I have been planning something like this for [Ebenstahl](https://machdyne.com/product/ebenstahl-storage-device/) and [Kaltstahl](https://machdyne.com/product/kaltstahl-storage-device/) so I'm interested to see your implementation.

rcmcdonald91, 2025-01-31:
It would be neat to have a basic file explorer in addition to the editor (a hex mode would be nice too) on the tty for systems that lack 1) fuse or 2) os/kernel support. Or even use the tty for entering an encryption passphrase or similar before allowing access to the FRAM. Lot's of neat possibilities here This is a fun board. My first real embedded work

rcmcdonald91, 2025-02-03:
This also supplants the need of the `bs` tool. `dd` and your hashing utility of choice works just as well.

rcmcdonald91, 2025-02-06:
After some more thought, I had another idea...

Since FRAM media doesn't operate on block boundaries, the only real benefit of exporting as a block device is for interoperability with existing tools (e.g. `dd`) and posix i/o APIs.

But...

What if we instead emulated a CH341 usb bus converter device (or similar), which would present as a `/dev/spidevN`. There are existing drivers in Linux and BSDs for these devices, so it would just(tm) be a matter of picking one to emulate.

machdyne, 2025-02-06:
I agree, the block device could be useful in many cases, even if 8KB isn't big enough for files.

Currently there are two ways to access the data besides the editor: the USB vendor class interface (used by bs.c) and [SRWP](https://github.com/binqbit/serialport_srwp) over USB-CDC (used by srwp.py).

I would like to create a SDK for accessing the vendor class interface, which is potentially very fast. Maybe having a SDK or library would be almost as good as spidev from a development perspective.

SRWP is slower, but it works over the serial connection and can still transfer the 8KB in under a second.

machdyne, 2025-03-05:
There is now a very minimal [USB-MSC implementation for Ebenstahl](https://github.com/machdyne/ebenstahl). I haven't yet implemented the LUN<->socket mapping.

It will probably make sense to use the Ebenstahl firmware for Kaltstahl (and maybe Blaustahl) when USB-MSC is desired.

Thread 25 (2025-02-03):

srwp example not working correctly

lwertzui, 2025-02-03:
When i try to run `python3 srwp.py read 0 50`or any size until around ~600 i just get `Reading <size> bytes from address 0
Data: b'' `, sometimes i get some data with `\x00\x00\x00\x00\x00\x00\x00\x00` where i see dots in screen, but even that isn't guaranteed, the echo command works directly after plugging my blaustahl in and only once, and even then i just get `Echoing: test b'\x1b[24'` or sometimes `Echoing: test b'\x1b[1;'`, sometimes `Echoing: test b''` or even `Echoing: test b'aaaa'`

machdyne, 2025-02-03:
Hi. I don't think this is mentioned anywhere, but srwp needs the 0.0.7 firmware to work correctly. If you're already using 0.0.7 then it may be a bug.

lwertzui, 2025-02-03:
that would explain everything, i just got mine, i don't know what the current revision is being shipped with, going to compile and upload newest, does flashing it work like a pi pico or are there any quirks i need to look out for?

lwertzui, 2025-02-03:
Ah no i see now, just read the README...

lwertzui, 2025-02-03:
seems to work now, I'm assuming the `\x00\x00` thing is intended?

machdyne, 2025-02-03:
I think Python displays non-printable characters as hex, and the data should be all zero by default.

lwertzui, 2025-02-03:
right

Closed 2025-02-03.

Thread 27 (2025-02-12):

Idea: Store FRAM size in the firmware

daniel156161, 2025-02-12:
I noticed that the bs tool currently reads only the fram size of 8192 and they is no way to change it, just only compile it again
with a bigger size set at BS_FRAM_SIZE

would it not be easier to store it in the Firmware of the Blaustahl / Kaltstahl Storage Device

then the bs / srwp just neat to ask the device for the size and all done
it will always read the full fram

machdyne, 2025-02-13:
Good idea. I have implemented this in the firmware, but have not yet generated new images so you'd need to build from source to test it.

There is now an SRWP command 0x0a that returns the size, and you can see it with:

```
python3 srwp.py info
```

Note that 512 bytes at the end of FRAM is reserved for metadata (needed for encryption), but the backup utilities should definitely copy the entire memory, including the metadata.

It would be nice to determine the FRAM size at power-on, so that it doesn't need to be hardcoded in firmware. That way only one set of firmware images would need to be maintained.

The 2Mbit FRAM has an RDID command that can be used for detection, otherwise it can fallback to the 8KB mode. There can be an override for mods that use other FRAM chips.

I will look into this further but it will require quite a few changes and testing.

machdyne, 2025-02-13:
There seems to be an issue with the current srwp.py, I wonder if anyone else is seeing this:

```
sw/srwp.py", line 53
    raise ValueError(f"More than one device found:\n\t{"\n\t".join(devices)}\nPlease specify the correct device with the --devices option or by setting the device argument.")
                                                         ^
SyntaxError: unexpected character after line continuation character
```

daniel156161, 2025-02-13:
that's stage, i tested it on my computer with
```
Linux Kernel: 6.13.0-1
Python: 3.13.1
```
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

can i ask how you got the error and what are you running?

machdyne, 2025-02-13:
Running the script in any form seems to cause that error with Python 3.10.16.

It does work fine with 3.13.1.

daniel156161, 2025-02-13:
okay reworked the error message block

tested in conda with Python 3.10.16

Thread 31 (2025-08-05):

Device does not show up on computer after adding updating firmware

ReDew96, 2025-08-05:
I tried to update the firmware to [blaustahl_cdconly-0.0.9.uf2](https://github.com/machdyne/blaustahl/blob/main/firmware/blaustahl_cdconly-0.0.9.uf2) by dragging the file into the device while in UF2 bootloader mode. When I did that the device seemed to disappear from my computer and now the blue light is always on and nothing shows up.

What gives?

ReDew96, 2025-08-06:
Since I have the kaltstahl device, I wonder if using the blaustahl firmware was the issue or not since it ships with Blaustahl firmware ([USB-MSC support](https://github.com/machdyne/kaltstahl/issues/2))

machdyne, 2025-08-06:
Kaltstahl does use the Blaustahl firmware, but it's compiled with a different FRAM_SIZE option.

You should always be able to get back to the UF2 bootloader by removing the enclosure and holding the button while inserting the device.

The firmware that ships with Kaltstahl is here:

https://github.com/machdyne/kaltstahl/tree/main/firmware

ReDew96, 2025-08-06:
I missed that detail (hold the button while plugging it in). That worked.

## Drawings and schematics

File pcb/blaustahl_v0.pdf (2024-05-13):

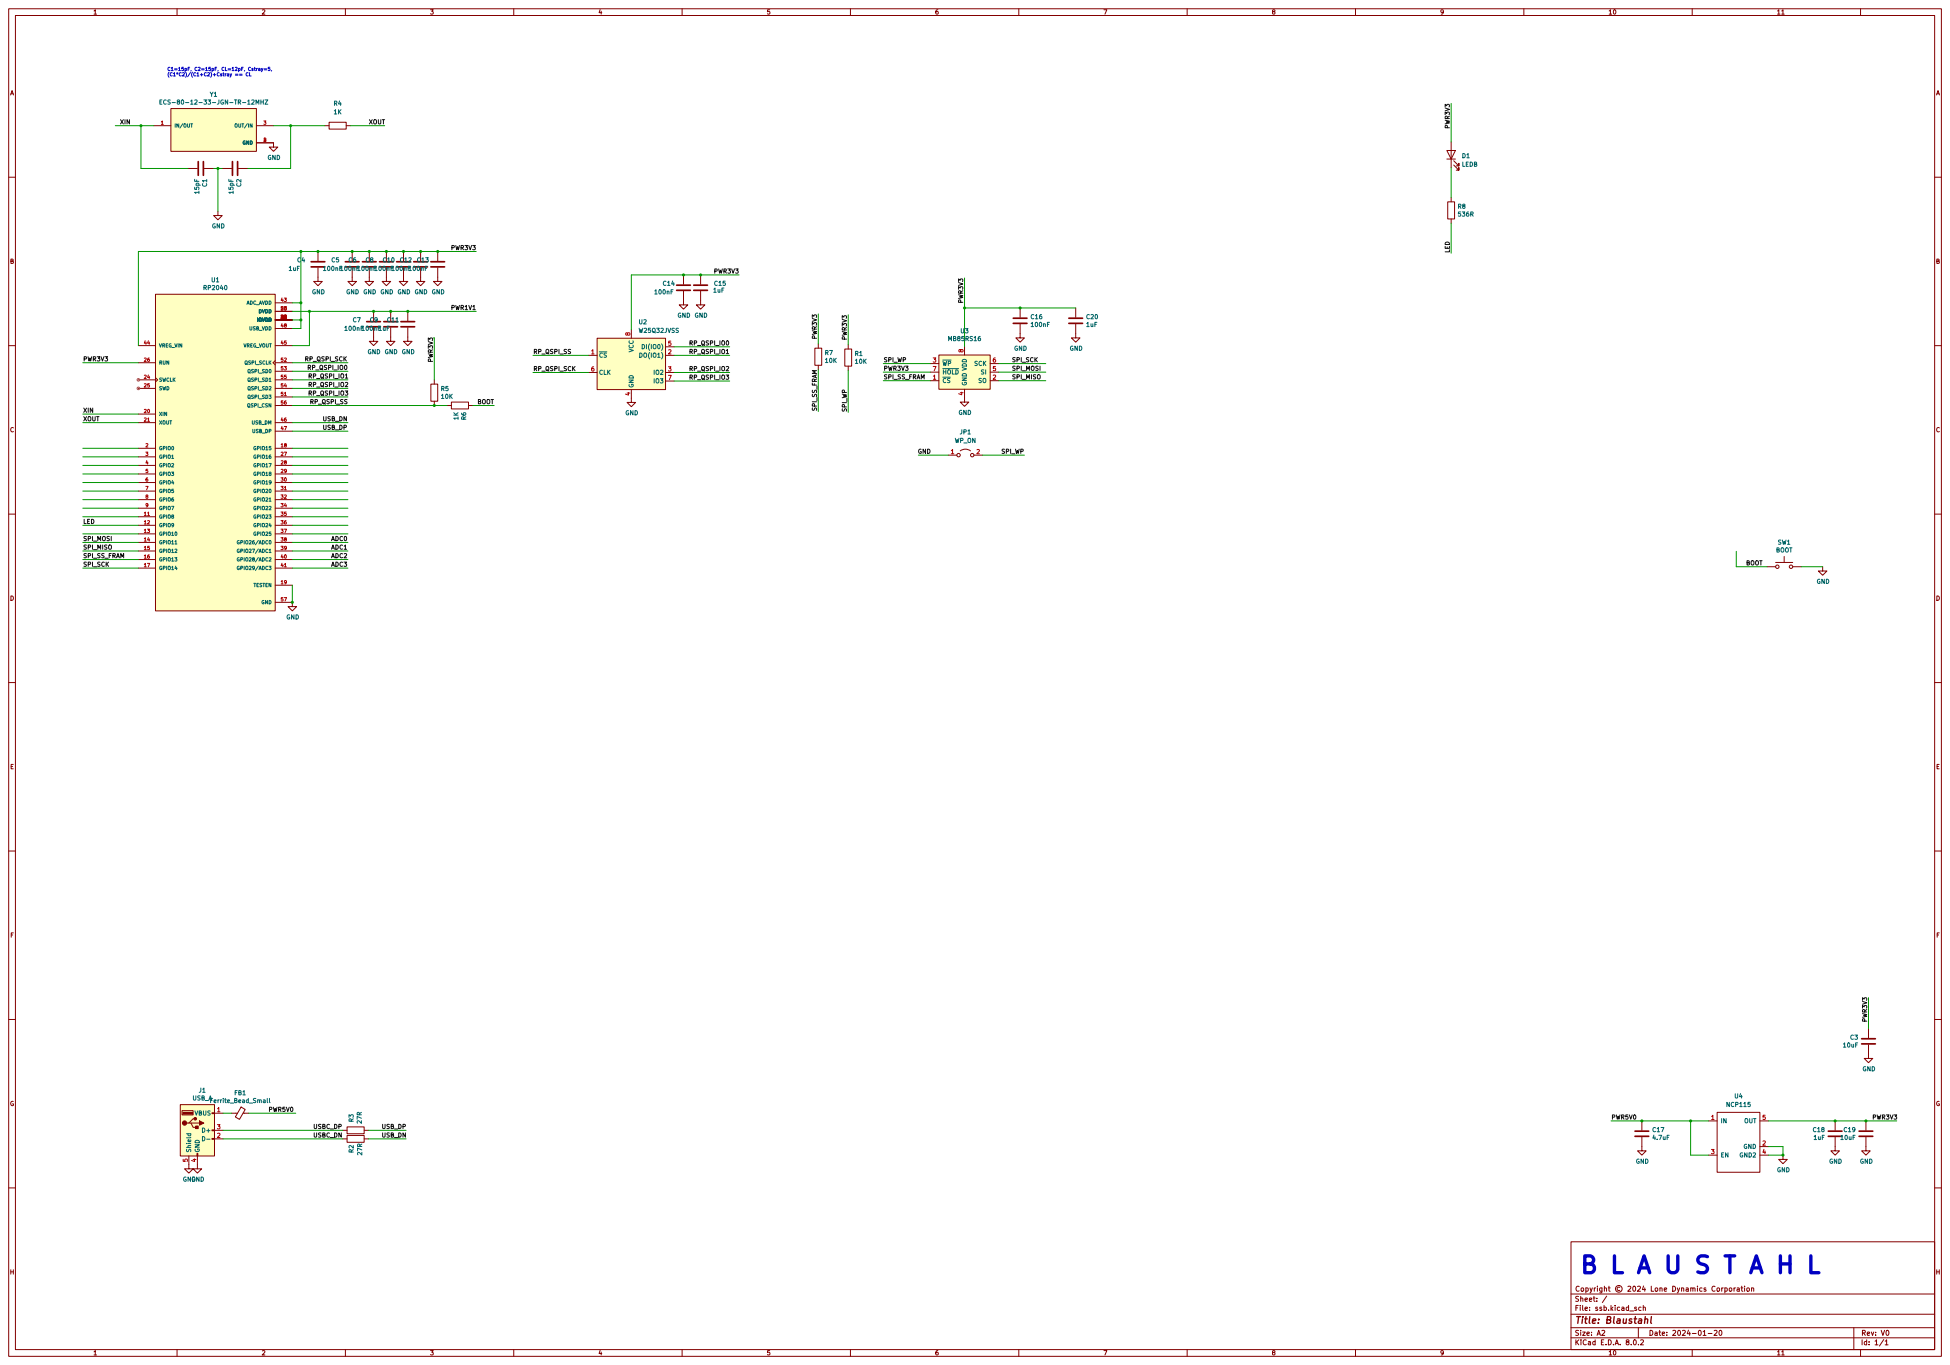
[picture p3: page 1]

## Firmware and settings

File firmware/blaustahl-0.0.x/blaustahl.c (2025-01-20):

/**
 * Copyright (c) 2020 Raspberry Pi (Trading) Ltd.
 * Copyright (c) 2024 Lone Dynamics Corporation <info@lonedynamics.com>
 *
 * SPDX-License-Identifier: BSD-3-Clause
 *
 * Blaustahl Firmware (work-in-progress)
 *
 */

#include <stdio.h>
#include <stdlib.h>
#include <stdarg.h>
#include <strings.h>
#include <string.h>

// Pico
#include "pico/stdlib.h"
#include "hardware/spi.h"
#include "hardware/watchdog.h"
#include "pico/binary_info.h"
#include "pico/multicore.h"
#include "pico/bootrom.h"

#include "hardware/pwm.h"
#include "hardware/pll.h"
#include "hardware/clocks.h"
#include "hardware/structs/pll.h"
#include "hardware/structs/clocks.h"

#include "tusb.h"

#include "blaustahl.h"
#include "editor.h"
#include "fram.h"

void core1_main(void);

void init_blaustahl(void);
bool init_done = false;

#ifndef CDCONLY
void blaustahl_task(void);

void blaustahl_task() {

	uint8_t buf[64];

	if (!tud_vendor_available()) return;

	uint32_t len = tud_vendor_read(buf, 64);

/*
	char tmp[256];
	sprintf(tmp, "RX %d bytes from host\r\n", len);
	tud_cdc_write_str(tmp);
	sprintf(tmp, "[%x %x %x %x]\r\n", buf[0], buf[1], buf[2], buf[3]);
	tud_cdc_write_str(tmp);
	tud_cdc_write_flush();
*/

	if (buf[0] == BS_CMD_NOP) {
	}

	if (buf[0] == BS_CMD_READ_BYTE) {
		int addr = buf[1] << 8 | buf[2];
      uint8_t lbuf[64];
      bzero(lbuf, 64);
		fram_read(lbuf, addr, 1);
      tud_vendor_write(lbuf, 64);
      tud_vendor_flush();
	}

	if (buf[0] == BS_CMD_WRITE_BYTE) {
		int addr = buf[1] << 8 | buf[2];
		fram_write_enable();
		fram_write(addr, buf[3]);
	}

}
#endif

void init_blaustahl(void) {

	printf("init_blaustahl\r\n");

	// init LED
	gpio_init(BS_LED);
	gpio_set_dir(BS_LED, 1);
	gpio_set_function(BS_LED, GPIO_FUNC_PWM);
	gpio_set_outover(BS_LED, GPIO_OVERRIDE_INVERT);

	uint slice_num = pwm_gpio_to_slice_num(BS_LED);
	pwm_set_wrap(slice_num, 499);
	pwm_set_chan_level(slice_num, BS_LED, LED_STARTUP);
	pwm_set_clkdiv_int_frac(slice_num, 250, 0);
	pwm_set_enabled(slice_num, true);

	// init FRAM
	fram_init();

}

int main(void) {

	// set the sys clock to 120mhz
	set_sys_clock_khz(120000, true);

	// init tinyusb
	tud_init(BOARD_TUD_RHPORT);

	// init stdio
	stdio_usb_init();

	// init hardware
	init_blaustahl();

	// start editor on second core
   multicore_reset_core1();
   multicore_launch_core1(core1_main);

	// handle USB tasks
	while (1) {

		tight_loop_contents();
		tud_task();
#ifndef CDCONLY
		blaustahl_task();
#endif

	}

	return 0;

}

void core1_main(void) {

	sleep_ms(10);

	while (true) {
		if (!init_done && tud_cdc_connected()) {
			init_done = true;
			editor_init();
		} else {
			editor_yield();
		}
	}

}

int cdc_getchar(void) {
	uint8_t buf[1];
	if (tud_cdc_connected() && tud_cdc_available()) {
		uint32_t count = tud_cdc_read(buf, 1);
		if (count)
			return((int)buf[0]);
		else
			return(EOF);
	} else {
		return(EOF);
	}
}

void cdc_putchar(const char ch) {
	if (tud_cdc_connected() && tud_cdc_write_available()) {
		tud_cdc_write_char(ch);
		tud_cdc_write_flush();
	}
}

// control LED
void blaustahl_led(uint16_t intensity) {
	pwm_set_gpio_level(BS_LED, intensity);
}

// enter DFU mode
void blaustahl_dfu(void) {
	reset_usb_boot(0, 0);
}

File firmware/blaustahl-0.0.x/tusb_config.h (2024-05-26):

/*
 * The MIT License (MIT)
 *
 * Copyright (c) 2019 Ha Thach (tinyusb.org)
 * Copyright (c) 2023 Lone Dynamics Corporation
 *
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
 */

#ifndef _TUSB_CONFIG_H_
#define _TUSB_CONFIG_H_

#ifdef __cplusplus
 extern "C" {
#endif

//--------------------------------------------------------------------+
// Board Specific Configuration
//--------------------------------------------------------------------+

// RHPort number used for device can be defined by board.mk, default to port 0
#ifndef BOARD_TUD_RHPORT
#define BOARD_TUD_RHPORT      0
#endif

// RHPort max operational speed can defined by board.mk
#ifndef BOARD_TUD_MAX_SPEED
#define BOARD_TUD_MAX_SPEED   OPT_MODE_DEFAULT_SPEED
#endif

//--------------------------------------------------------------------
// Common Configuration
//--------------------------------------------------------------------

// defined by compiler flags for flexibility
#ifndef CFG_TUSB_MCU
#error CFG_TUSB_MCU must be defined
#endif

#ifndef CFG_TUSB_OS
#define CFG_TUSB_OS           OPT_OS_NONE
#endif

#ifndef CFG_TUSB_DEBUG
#define CFG_TUSB_DEBUG        0
#endif

// Enable Device stack
#define CFG_TUD_ENABLED       1

// Default is max speed that hardware controller could support with on-chip PHY
#define CFG_TUD_MAX_SPEED     BOARD_TUD_MAX_SPEED

/* USB DMA on some MCUs can only access a specific SRAM region with restriction on alignment.
 * Tinyusb use follows macros to declare transferring memory so that they can be put
 * into those specific section.
 * e.g
 * - CFG_TUSB_MEM SECTION : __attribute__ (( section(".usb_ram") ))
 * - CFG_TUSB_MEM_ALIGN   : __attribute__ ((aligned(4)))
 */
#ifndef CFG_TUSB_MEM_SECTION
#define CFG_TUSB_MEM_SECTION
#endif

#ifndef CFG_TUSB_MEM_ALIGN
#define CFG_TUSB_MEM_ALIGN        __attribute__ ((aligned(4)))
#endif

//--------------------------------------------------------------------
// DEVICE CONFIGURATION
//--------------------------------------------------------------------

#ifndef CFG_TUD_ENDPOINT0_SIZE
#define CFG_TUD_ENDPOINT0_SIZE    64
#endif

//------------- CLASS -------------//
#define CFG_TUD_CDC               1
#define CFG_TUD_MSC               0
#define CFG_TUD_HID               0
#define CFG_TUD_MIDI              0
#ifndef CDCONLY
#define CFG_TUD_VENDOR            1
#endif

// CDC FIFO size of TX and RX
#define CFG_TUD_CDC_RX_BUFSIZE    (TUD_OPT_HIGH_SPEED ? 512 : 64)
#define CFG_TUD_CDC_TX_BUFSIZE    (TUD_OPT_HIGH_SPEED ? 512 : 64)

// Vendor FIFO size of TX and RX
// If not configured vendor endpoints will not be buffered
#define CFG_TUD_VENDOR_RX_BUFSIZE (TUD_OPT_HIGH_SPEED ? 512 : 64)
#define CFG_TUD_VENDOR_TX_BUFSIZE (TUD_OPT_HIGH_SPEED ? 512 : 64)


#ifdef __cplusplus
 }
#endif

#endif /* _TUSB_CONFIG_H_ */

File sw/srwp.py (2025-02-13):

#!/usr/bin/env python3

# Python example for using SRWP to communicate with Blaustahl
# see https://github.com/binqbit/serialport_srwp for protocol details

import serial
import logging
import glob
from serial.serialutil import SerialException

class BlaustahlSRWP:
    logger = logging.getLogger(__name__)

    def __init__(self, device:str|None='/dev/ttyACM0', fram_size:int|None=None):
        """
        Initializes the connection to the Storage device.

        :param device: Serial device path (default: '/dev/ttyACM0'). If None, attempts to auto-detect.
        :param fram_size: FRAM size in bytes. 
            - 8192 for Blaustahl Storage Device
            - 262144 for Kaltstahl Storage Device
        """
        if device is None:
            device = self.find_device()

        self.connect_over_serial(device)

        # Set FRAM Size Manuelly from User or else get it directly from Storage Device
        if fram_size:
            self.fram_size = fram_size
        else:
            self.read_fram_size()
            self.fram_size = int.from_bytes(self.read_fram_size(), "little")

    def connect_over_serial(self, device:str|None='/dev/ttyACM0'):
        self.srwp = serial.Serial(
            port=device,
            baudrate=115200,
            timeout=1,
            rtscts=False,
            dsrdtr=False,
            parity=serial.PARITY_NONE,
            stopbits=serial.STOPBITS_ONE
        )

    @staticmethod
    def find_device():
        """
        Finds the first available /dev/ttyACM device.
        :return: The path to the device as a string.
        :raises FileNotFoundError: If no device is found.
        :raises ValueError: If multiple devices are found.
        """
        devices = glob.glob('/dev/ttyACM*')
        if not devices:
            raise FileNotFoundError("No /dev/ttyACM device found.")
        elif len(devices) > 1:
            msg = 'More than one device found:'
            for device in devices:
                msg += f'\n\t {device}'
            msg += '\nPlease specify the correct device with the --devices option or by setting the device argument.'
            raise ValueError(msg)
        return devices[0]

    def flush(self):
        while self.srwp.in_waiting:
            data = self.srwp.read(4096)
            self.logger.debug(f"Flushed Data: {data}")

    def echo(self, msg:str):
        """
        Sends a message to the Device and reads back the response.
        :param msg: The message to send (ASCII-encoded)
        """
        self.flush()

        ba = bytearray()
        ml = len(msg)

        ba.extend(b'\x00')    # Enter SRWP mode
        ba.extend(b'\x00')    # Command: Echo
        ba.extend(ml.to_bytes(4, byteorder='little'))
        ba.extend(msg.encode(encoding="ascii"))

        self.srwp.write(ba)
        self.srwp.flush()

        data = self.srwp.read(ml)
        print(data)

    def read_fram(self, addr:int, size:int):
        """
        Reads `size` bytes from address `addr` on the FRAM chip.
        :param addr: Target address (4 bytes)
        :param size: Number of bytes to read
        """
        self.flush()

        ba = bytearray()
        ba.extend(b'\x00')    # Enter SRWP mode
        ba.extend(b'\x01')    # Command: Read FRAM
        ba.extend(addr.to_bytes(4, byteorder='little'))    # 4-byte address
        ba.extend(size.to_bytes(4, byteorder='little'))    # 4-byte size

        self.srwp.write(ba)
        self.srwp.flush()

        data = self.srwp.read(size)
        return data

    def write_fram(self, addr:int, data:bytes|bytearray):
        """
        Writes data to address `addr` on the FRAM chip.
        :param addr: Target address (4 bytes)
        :param data: Data to write (bytes or bytearray)
        """
        self.flush()

        ba = bytearray()
        ba.extend(b'\x00')    # Enter SRWP mode
        ba.extend(b'\x02')    # Command: Write FRAM
        ba.extend(addr.to_bytes(4, byteorder='little'))    # 4-byte address
        ba.extend(len(data).to_bytes(4, byteorder='little'))    # Data length
        ba.extend(data)    # Add data

        self.srwp.write(ba)
        self.srwp.flush()

    def read_fram_size(self):
        self.flush()

        ba = bytearray()
        ba.extend(b'\x00')    # Enter SRWP mode
        ba.extend(b'\x0a')    # Command: Read FRAM size

        self.srwp.write(ba)
        self.srwp.flush()

        data = self.srwp.read(4)
        return data

    def read_fram_retry(self, addr:int, size:int, max_retries:int=3):
        """
        Reads `size` bytes from address `addr` on the FRAM chip with retries.
        :param addr: Starting address
        :param size: Total number of bytes to read
        :param max_retries: Maximum number of retries for incomplete reads
        :return: All data as bytes
        """
        for attempt in range(max_retries):
            data = self.read_fram(addr, size)
            if len(data) == size:
                return data  # Successful read
            self.logger.warning(f"Incomplete read: Expected {size}, got {len(data)}. Retrying... (Attempt {attempt + 1})")
        raise IOError(f"Failed to read {size} bytes from FRAM after {max_retries} attempts")

    def read_fram_all(self, chunk_size:int=100):
        """
        Reads the entire content of the FRAM chip with retries.
        :return: All data on the FRAM chip as bytes.
        """
        data = bytearray()
        for offset in range(0, self.fram_size, chunk_size):
            chunk = self.read_fram_retry(offset, min(chunk_size, self.fram_size - offset))
            data.extend(chunk)
        return bytes(data)

    def write_fram_all(self, data:bytes|bytearray):
        """
        Writes the entire content to the FRAM chip.
        :param data: Data to write (must match the size of the FRAM).
        """
        self.write_fram(0, data)

    def write_chunks_fram_all(self, data:bytes|bytearray, chunk_size:int=100):
        """
        TESTING WRITE!!!!

        Writes the entire content to the FRAM chip in chunks.
        :param data: Data to write (must match the size of the FRAM).
        :param chunk_size: Size of each chunk to write.
        """
        for offset in range(0, len(data), chunk_size):
            chunk = data[offset : offset + chunk_size]
            try:
                self.write_fram(offset, chunk)
            except SerialException:
                self.logger.error(f"Failed to write chunk: {offset} - {chunk}")

    # Helper Functions
    def clear_fram(self):
        """
        Clears the entire FRAM chip.
        """
        for addr in range(self.fram_size + 1):
            self.write_fram(addr, b'\x00')

    def is_fram_empty(self):
        """
        Checks if the entire FRAM is empty (filled with '\x00').
        :return: True if the FRAM is empty, False otherwise.
        """
        data = self.read_fram_all()
        return all(byte == 0 for byte in data)
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

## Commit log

2024-05-13 add case
    [blaustahl.scad]
2024-05-16 improve case
    [blaustahl.scad]
2024-05-16 update case notes
    [blaustahl.scad]
2024-06-09 fix backspace bug when status bar is disabled
    [blaustahl.h]
2024-10-17 add python srwp example (not working yet)
    [srwp.py]
2025-01-20 increase osc startup delay; needed on some boards
2025-01-23 fix type in read_fram_all allow to find first Serial device if set to None in __init__ add function to check if fram is empty
    [srwp.py]
2025-01-23 add current shipping firmware
2025-01-23 TODO: - make read FRAM better getting not the full lenght sometimes - write to FRAM make device go into firmware update mode
2025-01-23 fix reading of data by makeing chunk window smaller
    [srwp.py]
2025-01-23 fix write to fram to not get any io errors or seial port already used errors
    [srwp.py]
2025-01-31 return error if multiple devices are found
    [srwp.py]
2025-01-31 make Mismatch error more clear that its from the imput data or file
    [srwp.py]
2025-01-31 allow to send the device into dfu mode
2025-01-31 fix typo of chunkks
    [srwp.py]
2025-02-11 fix left bracket issue
    [blaustahl.h]
2025-02-11 change find device text when found multiple devices
2025-02-21 add alt case / board step file
    [blaustahl.step, blaustahl_alt.scad]
2025-05-15 add improved case
    [blaustahl_neu.scad]
